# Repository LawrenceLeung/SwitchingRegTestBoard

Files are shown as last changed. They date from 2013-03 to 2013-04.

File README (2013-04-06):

Test board for MC34063AD switching reg

There are values in the schematic, but you should pick your own values.

See this helpful calculator to choose values:

http://dics.voicecontrol.ro/tutorials/mc34063/

Here's my first test (2013-03-30):
12.00 ±20% V
Vout =	5.17 V
Iout =	0.50 A
Vripple =	0.03 V
---
Vin min =	9.60 V
Ton / Toff =	1.39
Ton + Toff =	20.00 µs (micro seconds)
Toff =	8.36 µs (micro seconds)
Ton =	11.64 µs (micro seconds)
Ct =	465.53 pF
Ipk =	1.00 A
Rsc =	0.30 Ω
Lmin =	45.74 µH
Co =	100.00 µF

--- (My tweaked resistor values for what I have)
R2  = 1.5k	
R3 = ((Vout - 1.25) / 1.25) * R1 =	4.7kΩ

(using 5% resistors since that's what I got)

L1 = MULTICOMP - MCSDC0604-470KU - INDUCTOR, 47UH, 720MA, ±10%
L2 = BOURNS - SRN3015-1R0Y - INDUCTOR, 1UH, 2.35A, ±30%, 145MHZ
C1 = 470pf ceramic
C3 = 10uF tantalum
D1 = 821-B0520LW Schottky Diodes & Rectifiers 20 Volt 0.5 Amp 5.5 Amp IFSM
C2,4 = 100uF aluminum cap 0.3ohm ESR (647-UVR1V101MEA1TA)

Results: (Load: 13.6 Ohms, ~350mA ~1.7W)

~190mVpp ripple,  Freq: ~72kHZ
~230mVpp ripple,  Freq: ~72kHZ (Before second LC filter)

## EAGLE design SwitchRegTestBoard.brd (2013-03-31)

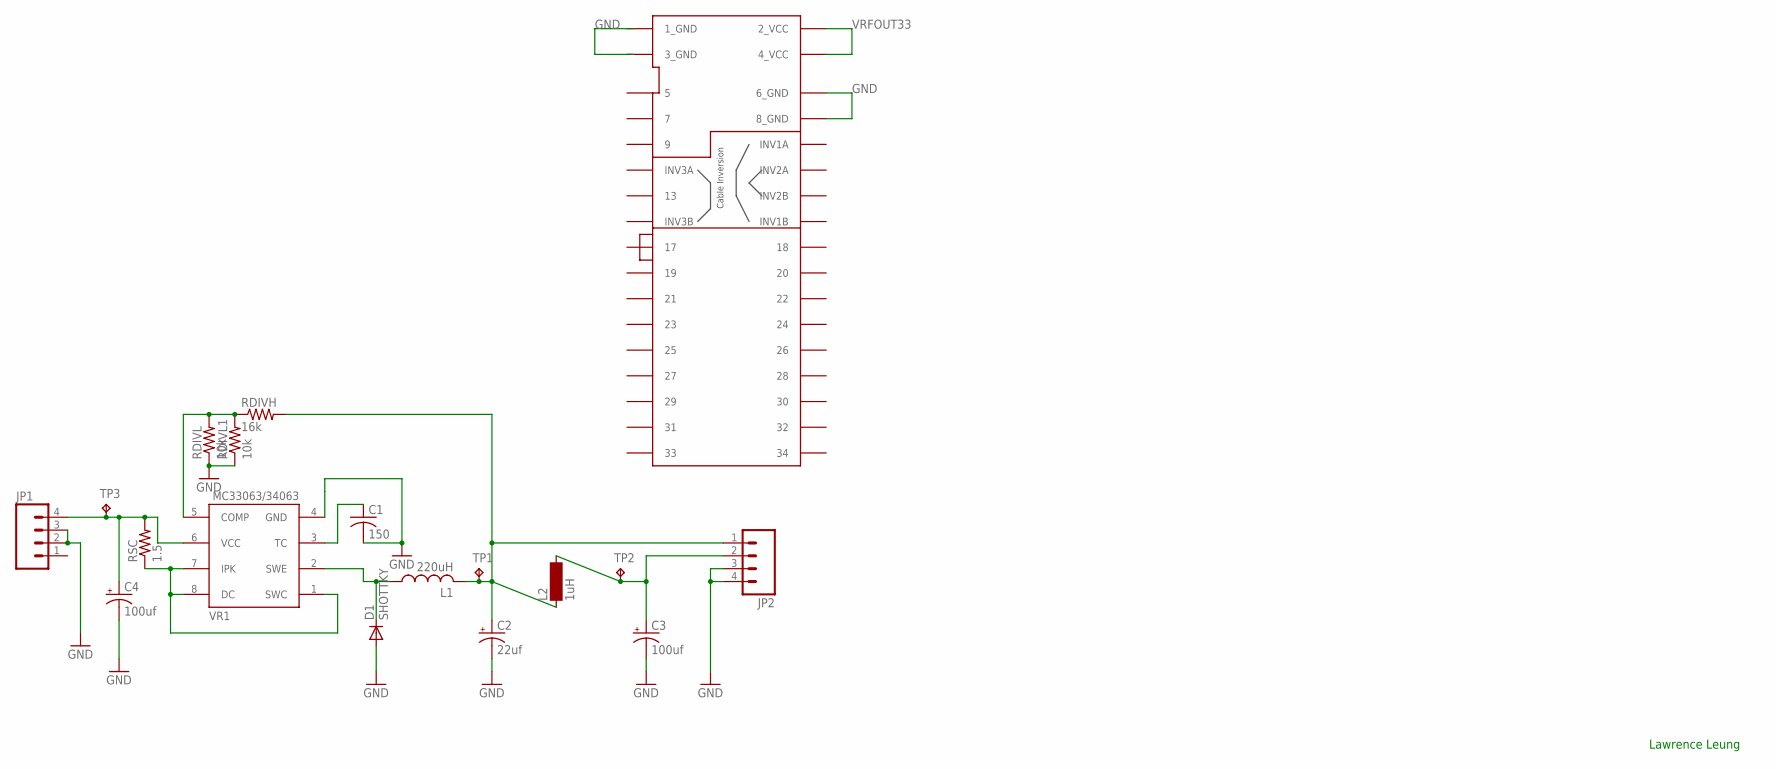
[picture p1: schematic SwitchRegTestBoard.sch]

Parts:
C1: 150; C0603
C2: 22uf; PANASONIC_C
C3, C4: 100uf; PANASONIC_C
D1: SHOTTKY; SOD-123
JP1, JP2: HEADER1X4SMD_LONGPADS; 1X04-SMD-LONG
L1: 220uH; L0707MM
L2: 1uH; SM-NE29
RDIVH: 16k; R0805
RDIVL, RDIVL1: 10k; R0805
RSC: 1.5; R1206
TP1, TP2, TP3: TPTP10R; TP10R
U$1: HEADER-525IDEB
VR1: MC34063AD; SO08

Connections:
1_GND: U$1.1_GND
3_GND: U$1.3_KEY_NC (3_GND)
DIVIDERCENTER: RDIVH.1, RDIVL.2, RDIVL1.2, VR1.5 (COMP)
GND: C1.2, C2.-, C3.-, C4.-, D1.A, JP1.2, JP1.3, JP2.3, JP2.4, RDIVL.1, RDIVL1.1, U$1.6_INUSE (6_GND), U$1.8_INDEX (8_GND), VR1.4 (GND)
unnamed: RSC.1, VR1.1 (SWC), VR1.7 (IPK), VR1.8 (DC)
unnamed: C1.1, VR1.3 (TC)
VIN: C4.+, JP1.4, RSC.2, TP3.TP, VR1.6 (VCC)
VR1L: D1.C, L1.1, VR1.2 (SWE)
VRFOUT33: C3.+, JP2.2, L2.2, TP2.TP, U$1.2_DCD (2_VCC), U$1.4_DS3 (4_VCC)
VROUT33: C2.+, JP2.1, L1.2, L2.1, RDIVH.2, TP1.TP

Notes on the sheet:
Lawrence Leung

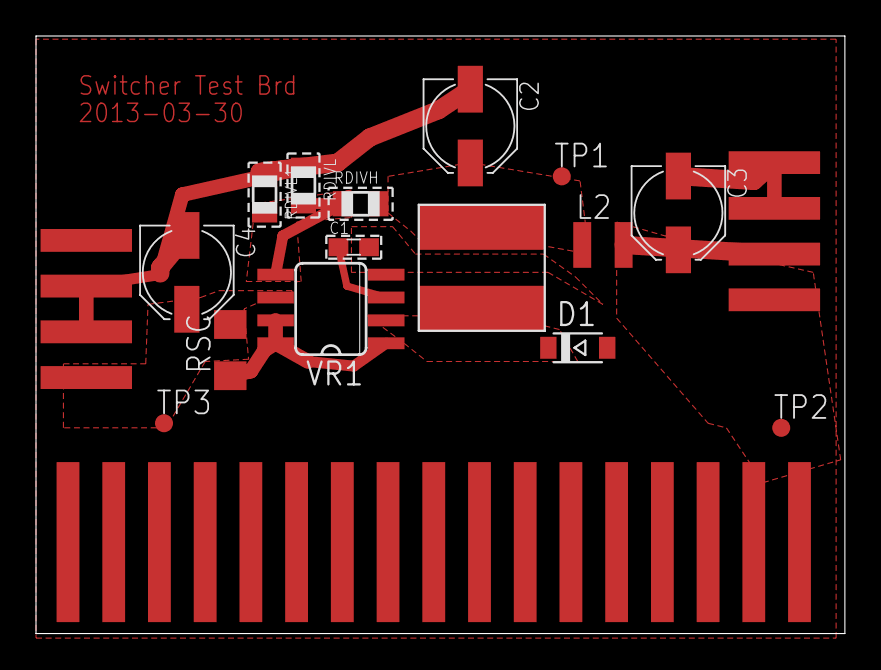
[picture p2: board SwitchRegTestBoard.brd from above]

Board: 2 copper layers, 44.9 x 33.2 mm, 18 parts (0 on the bottom side), 8 nets.

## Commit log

2012-04-28 Set values for 3.3v out. Make sense resistor 1206 and improve documentation
    [SwitchRegTestBoard.brd, SwitchRegTestBoard.sch]
2012-05-09 Make the inductors larger
    [SwitchRegTestBoard.brd, SwitchRegTestBoard.sch]
2012-05-12 Add PATA cable header
    [SwitchRegTestBoard.brd, SwitchRegTestBoard.sch]
2013-02-27 Switch resistor to 0805, add test points, hatch gnd
    [SwitchRegTestBoard.brd, SwitchRegTestBoard.sch]
2013-03-24 Prepare foor etch
    [SwitchRegTestBoard.brd]
2013-03-31 star ground around switcher. Additional resistor pad for low side of divider for tweaking resistance
    [SwitchRegTestBoard.brd, SwitchRegTestBoard.sch]
2013-03-31 polygon tuning
    [SwitchRegTestBoard.brd]
